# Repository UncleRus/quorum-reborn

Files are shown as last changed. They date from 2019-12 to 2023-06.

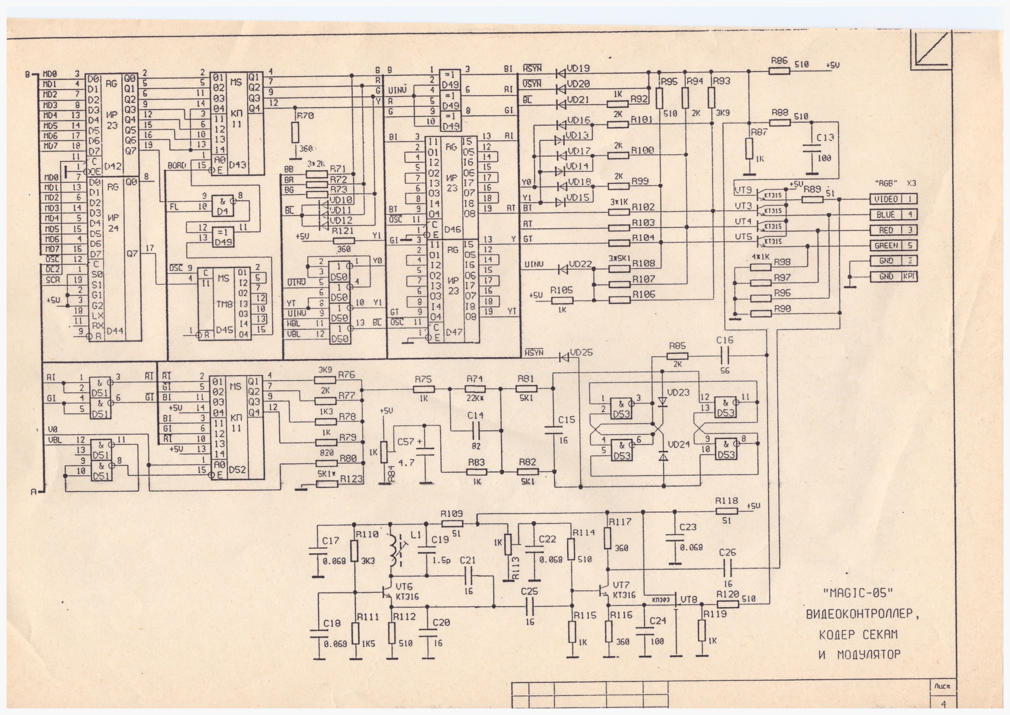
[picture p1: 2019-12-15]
resources/Magic-05/Schematics/Axon/p4.jpg

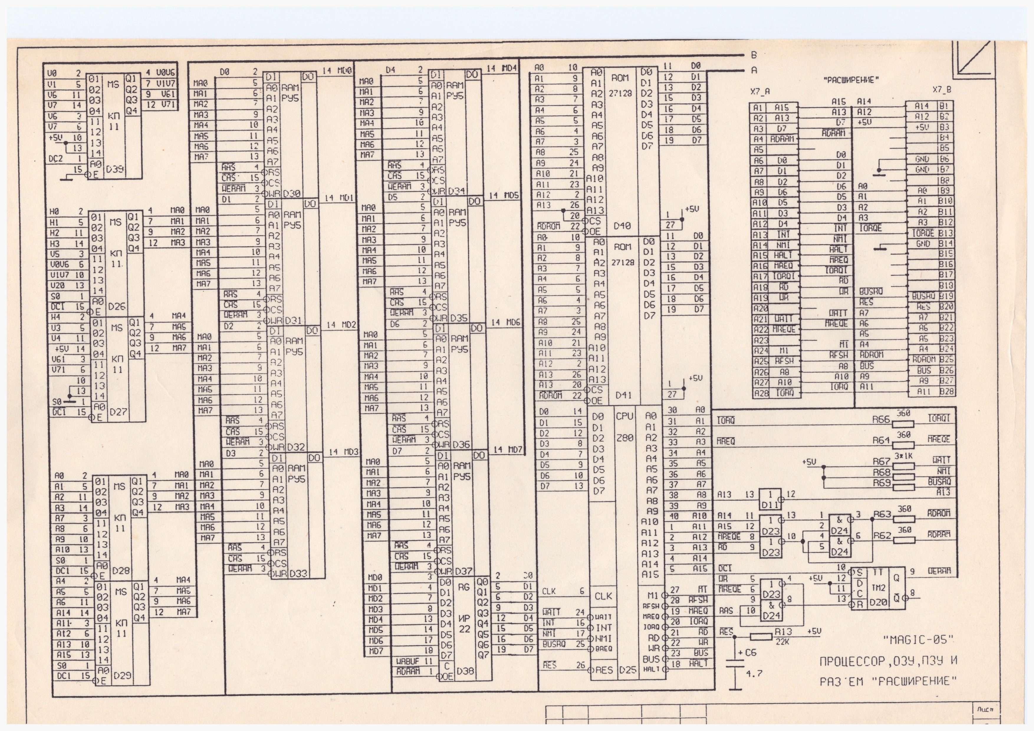
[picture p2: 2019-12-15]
resources/Magic-05/Schematics/Axon/p3.jpg

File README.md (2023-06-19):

# Quorum Reborn

## Russian

[English](#english)

Старая и восстановленная документация для компьютеров ZX Spectrum "Кворум" и "Магик".

### Что такое "Кворум"?

"Кворум" — домашний компьютер, клон ZX Spectrum на советской элементной базе.
Разработан в Свердловске/Екатеринбурге Камилем Каримовым, выпускался заводами
"Вектор", "УОМЗ". Все машины имеют кодер SECAM.

Поддержка "Кворума" встроена в эмуляторы UnrealSpeccy и ZXMAK2.

#### Модели компьютеров

- **Magic-05** — Клон ZX Spectrum 48K с расширенной клавиатурой и портом Centronics.
- **Кворум 64** — Модифицированная версия «Magic-05» с доступным ОЗУ объёмом 64 КБ
   (дополнительные 16 КБ использовались как «теневое» ОЗУ) и измененной адресацией
   дополнительного порта расширенной клавиатуры.
- **Кворум 128** — Клон ZX Spectrum 128K без AY-3-8910. Схема построена на БМК
   КБ01ВГ1-2. В ПЗУ присутствует встроенный тест, монитор и копировщик. Возможность
   работы как в TR-DOS, так и в CP/M. На задней стенке корпуса компьютера располагались
   разъёмы для подключения внешнего блока питания, Kempston и Sinclair джойстиков,
   принтера, магнитофона, телевизора и монитора, а также разъём системной шины для
   подключения внешнего контроллера дисковода.
- **Кворум 128+** — Модификация «Кворум 128» со встроенным 3-дюймовым дисководом,
   контроллером дисковода и звуковым синтезатором AY-3-8910.
- **Кворум БК04** — Выпускался УОМЗ. Клон ZX Spectrum 48K. Имеет кодер SECAM с
   ВЧ-модулятором.
- **Кворум БК05** — Выпускался УОМЗ. Клон ZX Spectrum 48K на БМК КБ01ВГ1-2 и
   однокристальном SECAM-кодере. На плате реализован порт принтера, но отсутствует
   разъем.

### Состав репозитория

- **kicad** - Проекты KiCad для
   - Magic-05,
   - Кворум 64,
   - Кворум 128,
   - Кворум БК04,
   - контроллера дисковода
- **resources** - Старая документация, прошивки, фотографии, софт

### Проекты KiCad

Для работы с ними необходим KiCad версии >= 7.0.
Также в каждом проекте, в подкаталогах /plot лежат схемы, экспортированные в формат PDF.

### Ссылки

https://github.com/atsidaev/quorum-cpm - Исходники CP/M для "Кворума", документация 
по программированию.

## English

Old and restored documentation for ZX Spectrum computers "Quorum" and "Magic".

### What is "Quorum"?

"Quorum" is a home computer, a clone of the ZX Spectrum built with Soviet ICs.
It's developed in Yekaterinburg f.k.a. Sverdlovsk by Kamil Karimov and manufactured by "Vector" and "UOMZ"
factories. All models have built-in SECAM encoder.

Quorum is supported by UnrealSpeccy and ZXMAK2 emulators.

#### The lineup

- **Magic-05** — ZX Spectrum 48K clone with extended keyboard and Centronics port.
- **Quorum 64** — Modified version of "Magic-05" with 64 KB available RAM (additional
   16 KB is used as shadow RAM) and changed addressing of the extended keyboard
   additional port.
- **Quorum 128** — ZX Spectrum 128K clone without the AY-3-8910. The construction 
   is based on KB01VG1-2. The ROM contains a built-in test, monitor and copier.
   It has ability to work in both TR-DOS and CP/M. On the rear side of the computer
   case there were connectors for connecting an external power supply, Kempston and
   Sinclair joysticks, a printer, a tape recorder, a TV and a monitor, as well as a
   system bus connector for connecting an external floppy controller.
- **Quorum 128+** — Quorum 128 modification with a built-in 3-inch drive,
   floppy controller and sound synthesizer AY-3-8910.
- **Quorum БК04** — Produced by UOMZ. ZX Spectrum 48K clone. Has a SECAM encoder with
   RF modulator.
- **Quorum БК05** — Produced by UOMZ. ZX Spectrum 48K clone on BMK KB01VG1-2 and
   single-chip SECAM encoder. The board has a printer port, but no connector.

### Repository contents

- **kicad** - KiCad projects for
   - Magic-05,
   - Quorum 64,
   - Quorum 128,
   - Quorum БК04,
   - Floppy Disk Drive
- **resources** - Old docs, firmware, images, software.

### KiCad Projects

To work with projects you'll need KiCad version >= 7.0.
Also in each project, in the /plot subdirectory there are schematic diagrams 
exported in PDF format.

### Links

https://github.com/atsidaev/quorum-cpm - CP/M sources for Quorum,
development docs.

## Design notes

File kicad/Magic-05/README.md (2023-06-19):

## Схема Magic-05

Проект содержит оригинальную схему Magic-05 с исправленными ошибками без модификаций.

По имеющимся данным компьютер разработан НПО "Интеграл" Сергеем Жаворонковым, Андреем Вычегжаниным, Юрием Серёгиным
под руководством Анатолия Хомени.

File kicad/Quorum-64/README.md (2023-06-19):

## Схема Кворум 64

  - Этот каталог содержит оригинальную схему "Кворум 64" с исправленными ошибками без модификаций
  - Подкаталог `fix-brightness` содержит вариант схемы "Кворум 64" с исправленной ошибкой атрибута яркости у черного

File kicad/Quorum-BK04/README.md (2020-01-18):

## Кворум-БК04

В наличии два варианта схемы: 

- **Quorum-BK04.pro** - Оригинальная заводская схема
- **Quorum-BK04-mods.pro** - Схема с модификациями (порт FF, пентагоновские времянки)

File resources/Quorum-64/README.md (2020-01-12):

## Кворум-64

> Да, это одна и та же схемотехника,кроме адресации дополнительного порта расширенной клавиатуры.
> В Магике (во всех моделях) дополнительный порт адресуется кодом 0xFC, а в Кворумах 0x7E.
> Заводские платы "Магик-5" были доработаны в части адресации этого порта и в них установлены ПЗУ с прошивкой "Кворум 64".
> Особенность прошивки этих моделей именно в части наличия поддержки расширенной клавиатуры, а также русификации, которая также выполнена по-разному.

*Kamil Karimov (Caro)*

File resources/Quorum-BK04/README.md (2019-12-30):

## Кворум БК-04

Первый из серии Кворумов - модель БК-04.
Выпускался УОМЗ (Уральский Оптико-механический завод), с 1992 по 1993 год.
Имеет 48 кб ОЗУ и 16 кб. ПЗУ. Прошивка русифицирована и расчитана на работу с 88-клавишной клавиатурой.
Дополнительная матрица 6*8 подключена через порт 7Eh. Встроенный кодер СЕКАМ и TV-модулятор.

На плате предусмотрено место для распайки стандартного разьема принтера DB25F.
Порты принтера совместимы с ZX-LPrint II. Все процедуры работы с принтером в прошивке переделаны для работы с этим интерейсом.

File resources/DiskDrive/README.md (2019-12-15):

## Схемы контроллера дисковода CP/M-TRDOS для Кворума

1) disk5ram.png - исходная схема, работающая с прошивкой
                  заливаемой в фоновое ОЗУ;
2) disk5emu.png - доработанная схема, работающая и с ОЗУ
                  и с ПЗУ;
3) disk5buf.png - схема буфера;
4) disk5raz.png - размещение элементов контроллера;
5) disk5trd.png - доработанная схема с адресацией портов
                  как в стандартном TRDOS.

*18/05/09*
*Kamil Karimov (caro)*

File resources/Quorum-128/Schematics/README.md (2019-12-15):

## Схема Кворума 128.

Основой схемы является микросхема КБ01ВГ1-2 производства завода Микрон г. Зеленоград.
Используется также микросхема кодера Secam, изготовленная в Екатеринбурге по ТЗ фирмы
"Кворум".

*Kamil Karimov*
*k2k@list.ru*

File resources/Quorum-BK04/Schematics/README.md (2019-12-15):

# Схема и монтажка компьютера "Кворум БК-04"

Разработка фирмы "Кворум" 1991 года.
Производство УОМЗ 1991-1994 гг.

На схеме приведены возможные доработки:

1) обеспечивающие совместимость с времянками Пентагона;
2) порт FF;
3) турбирование за счет ускорения процессора в цикле REFRESH.

*Kamil Karimov (caro)*

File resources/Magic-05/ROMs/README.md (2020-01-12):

## Прошивки для Magic-05

- MAGIC5_1.ROM - последняя версия прошивки, предоставлена Камилем Каримовым
- magic91.rom - вариант прошивки, предоставлен Камилем Каримовым
- magic5_1092350.rom - прошивка, считанная с ПЗУ компьютера с серийным номером 1092350

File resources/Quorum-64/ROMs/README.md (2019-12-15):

# Прошивки для "Кворума БК-04" производства УОМЗ и "Кворум 64" производства ПО Вектор.

 - QU4i1993.rom - только BASIC
 - QU4v93t4.rom - Basic и TR-DOS 5.04T не эмулятор
 - QU4v93tb.rom - Basic и TR-DOS 5.03E эмулятор
 - Quorum_64_08930726.rom - Прошивка, считанная с Кворума-64 с серийным номером `08 93 0726`

В прошивке Basic для работы с контроллером дисковода (с точкой в заставке BASIC) предусмотрен
"горячий" выход в TRDOS по нажатию клавиши NMI с предварительно нажатой клавишей Caps Shift.

*Kamil Karimov (caro)*
*14.04.2009*

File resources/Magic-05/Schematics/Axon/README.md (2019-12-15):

## Схема Магика-05

Схема предоставлена AlexCrush

### Ошибки

Схема содержит ряд ошибок:

 - Лист P1:
   
   - Неверные имена сигналов: HSIN, /HSIN, VSIN, /VSYN. 
     Должно быть: HSYN, /HSYN, VSYN, /VSYN соответственно.

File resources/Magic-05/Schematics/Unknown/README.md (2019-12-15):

## Magic-05

Еще один вариант схемы. Взят с форума https://zx-pk.ru

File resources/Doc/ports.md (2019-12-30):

# Порты Кворумов

Хотя при адресации портов используется неполная дешифрация адреса,
рекомендуется использовать указанные ниже адреса устройств при разработке 
своих программ.

## Порт управления памятью
Адрес **00H** [A7,A4,A0,/IORQ = 0]

Назначение разрядов порта (только запись):

- **D0 (F_RAM)** - управление фоновой страницей ОЗУ
  - 0 - включено ПЗУ
  - 1 - включена 0-ая страница ОЗУ
- **D1 (UP_S)** - (только для Кворум 64 с дисководом) переключатель страниц видео-ОЗУ
  - 0 - нижняя страница (4000H..5AFFH)
  - 1 - верхняя страница (C000H..DAFFH)
- **D2 (EX_ROM)** - (только для Кворум 128, в '128+' нет) управление расширенным ПЗУ (до 32 Кбайт)
  - 0 - включено основное ПЗУ
  - 1 - включено дополнительное ПЗУ
- **D3** - резерв
- **D4** - резерв
- **D5 (B_ROM)** - (в Кворум 64 не используется) разрешение BASIC-страницы ПЗУ
  - 0 - включена дополнительная страница ПЗУ
  - 1 - включена BASIC-страница ПЗУ
- **D6 (BLK_WR)** - (для Кворум 64 требуется доработка) блокировка записи в фоновое ОЗУ
  - 0 - запись в адреса с 0000..3FFFH разрешена
  - 1 - запись заблокирована, только чтение
- **D7 (TR_DOS)** - разрешение работы TRDOS из ПЗУ
  - 0 - TRDOS работает из фонового ОЗУ
  - 1 - разрешена работа из ПЗУ

## Порт Sрectrum 128
Адрес **7FFDH** [A15,A1,/IORQ = 0; A3,A4 = 1]

Назначение разрядов порта (только запись):

- **D0..D2 (NP_RAM)** - номер страницы ОЗУ, отображаемой на адреса
  с 0C000H до 0FFFFH
- **D3 (SCR_P)** - (для Кворум 128, 128+ в режиме BASIC) переключатель страниц видео-ОЗУ
  - 0 - нижняя страница (4000H.. в ОЗУ-5)
  - 1 - верхняя страница (C000H.. в ОЗУ-7)
- **D4 (B_PAG)** - управление страницами BASIC-ПЗУ
  - 0 - BASIC-128
  - 1 - BASIC-48
- **D5 (BLK_P)** - блокировка записи в порт SP_128
  - 0 - запись разрешена
  - 1 - запись заблокирована (снятие по сбросу)
- **D6 (EX_RAM)** (только для Кворум 256)
  - 0 - основное ОЗУ
  - 1 - дополнительный блок на 128 Кбайт
- **D7 (E2_RAM)** (только для Кворум 512)

## Порт CP/M
Адрес **80FDH** [A13,A1,/IORQ = 0; A15,A4,A3 = 1]

Этот порт реализован в ULA, используемом в Кворум 128 и Кворум 128+.
Запись в него разрешена только в случае первого обращения к нему после
начального сброса.

Назначение разрядов порта (только запись):

- **D0..D2 (NP_SCR)** - переключатель адреса начала видео-ОЗУ 
   (только в Кворум 128, 128+ в режиме CP/M)
  - 000 - 4000H
  - 001 - 6000H
  - 010 - 8000H
  - 011 - A000H
  - 100 - C000H
  - 101 - E000H
  - 110 - 0000H
  - 111 - 2000H
- **D3..D6** - не используются
- **D7 (EN_RAM)** - разрешение работы с фоновым ОЗУ
  - 0 - запрет работы с фоновым ОЗУ
  - 1 - в фоновое ОЗУ разрешена запись

## Порты клавиатуры

### Основной порт
Адрес **FEH** [A0,/IORQ = 0; A7,A4,A3 = 1]

Назначение разрядов порта (чтение):

- **D0..D4** - разряды сканирования клавиатуры
- **D5** - не используется (всегда 1)
- **D6** - разряд чтения с магнитофона
- **D7** - не используется (всегда 1)

Назначение разрядов порта (запись):

- **D0..D2** - код цвета бордюра
- **D3** - разряд записи на магнитофон
- **D4** - разряд управления звуком
- **D5..D7** - не используется

### Дополнительный порт
Адрес **7EH** [A7,A0,/IORQ = 0; A4,A3 = 1]

Назначение разрядов порта (чтение):

- **D0..D5** - разряды сканирования клавиатуры
- **D6..D7** - не используется (всегда 1)

## Порты контроллера дисковода

### Порт состояния/команд ВГ93
Адрес **80H** [A4,A3,A2,A1,A0,/IORQ = 0; A7 = 1]

### Порт номера текущей дорожки ВГ93
Адрес **81H** [A4,A3,A2,A1,/IORQ = 0; A7,A0 = 1]

### Порт номера сектора ВГ93
Адрес **82H** [A4,A3,A2,A0,/IORQ = 0; A7,A1 = 1]

### Порт данных ВГ93
Адрес **83H** [A4,A3,A2,/IORQ = 0; A7,A1,A0 = 1]

### Порт управления дисководом
Адрес **85H** [A4,A3,/IORQ = 0; A7,A2 = 1]

Назначение разрядов порта:

- **D0 (SEL_0)** 
  - 1 - выборка устройства A:
- **D1 (SEL_1)**
  - 1 - выборка устройства B:
- **D2 (резерв SEL_2)**
  - 1 - выборка устройства C:
- **D3 (резерв SEL_3)**
  - 1 - выборка устройства D:
- **D4 (SIDE)** - выбор стороны дискеты
  - 0 - верхняя головка дисковода
  - 1 - нижняя головка дисковода
- **D5 (MOTOR)**
  - 1 - включить привод дисковода
- **D6..D7** - резерв

## Порт Кэмпстон-джойстика.
Адрес **1FH** [A7,/IORQ = 0; A4,A3,A0 = 1]

Назначение разрядов порта (только чтение):

- **D0..D4** - разряды джойстика
  (при не подключенном джойстике всегда 0)
- **D5..D6** - не используется (всегда 0)
- **D7** - разряд готовности принтера
  (при не подключенном принтере всегда = 0)

## Порты принтера.

### Порт данных
Адрес **FBH** [A2,/IORQ = 0; A7,A4,A3,A0 = 1]

Запись в этот порт устанавливает линию 'Строб' в 1.

Назначение разрядов (только на запись):

**D0..D7** - байт данных, пересылаемый в принтер

### Порт формирователя строба
Адрес **7BH** [A7,A2,/IORQ = 0; A4,A3,A0 = 1]

Запись в этот порт устанавливает линию 'Строб' в 0.

### Порт готовности принтера
Адрес **1BH** [A7,/IORQ = 0; A4,A3,A0 = 1]

Назначение разрядов (только чтение):

- **D0..D6** - не используются (всегда 0)
- **D7** - линия готовности принтера
  - 0 - принтер готов
  - 1 - принтер занят

## Порты музыкального сопроцессора.

### Порт адресации регистров AY-3-8910/12

Адрес **FFFDH** [A1,/IORQ =0; A15,A14,A13,A4,/M1 = 1]

### Порт данных AY-3-8910/12

Адрес **BFFDH** [A14,A1,/IORQ =0; A15,A13,A4,/M1 = 1]

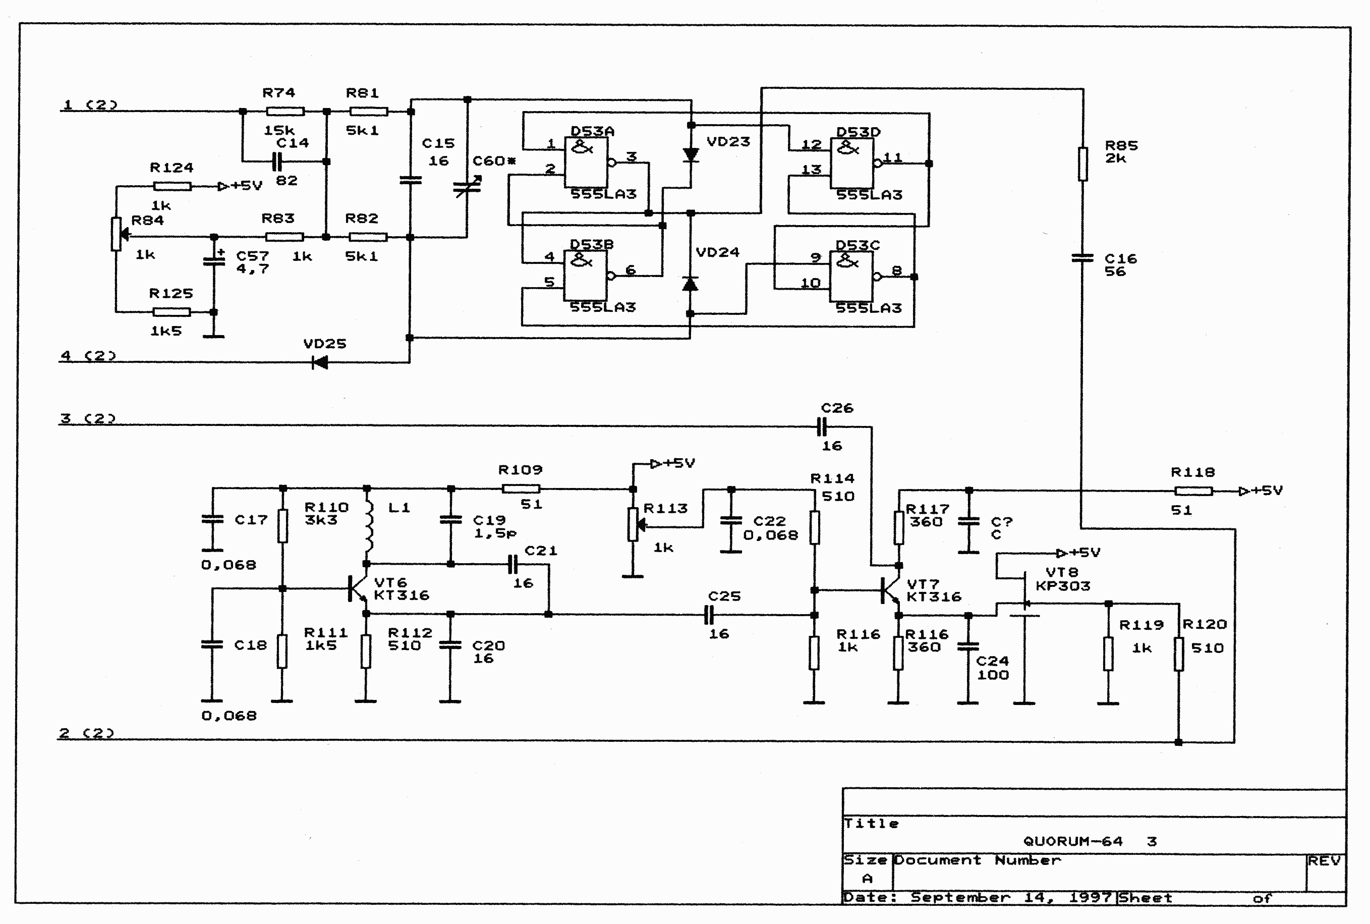
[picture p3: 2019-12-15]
resources/Quorum-64/Schematics/QU64_3.PNG

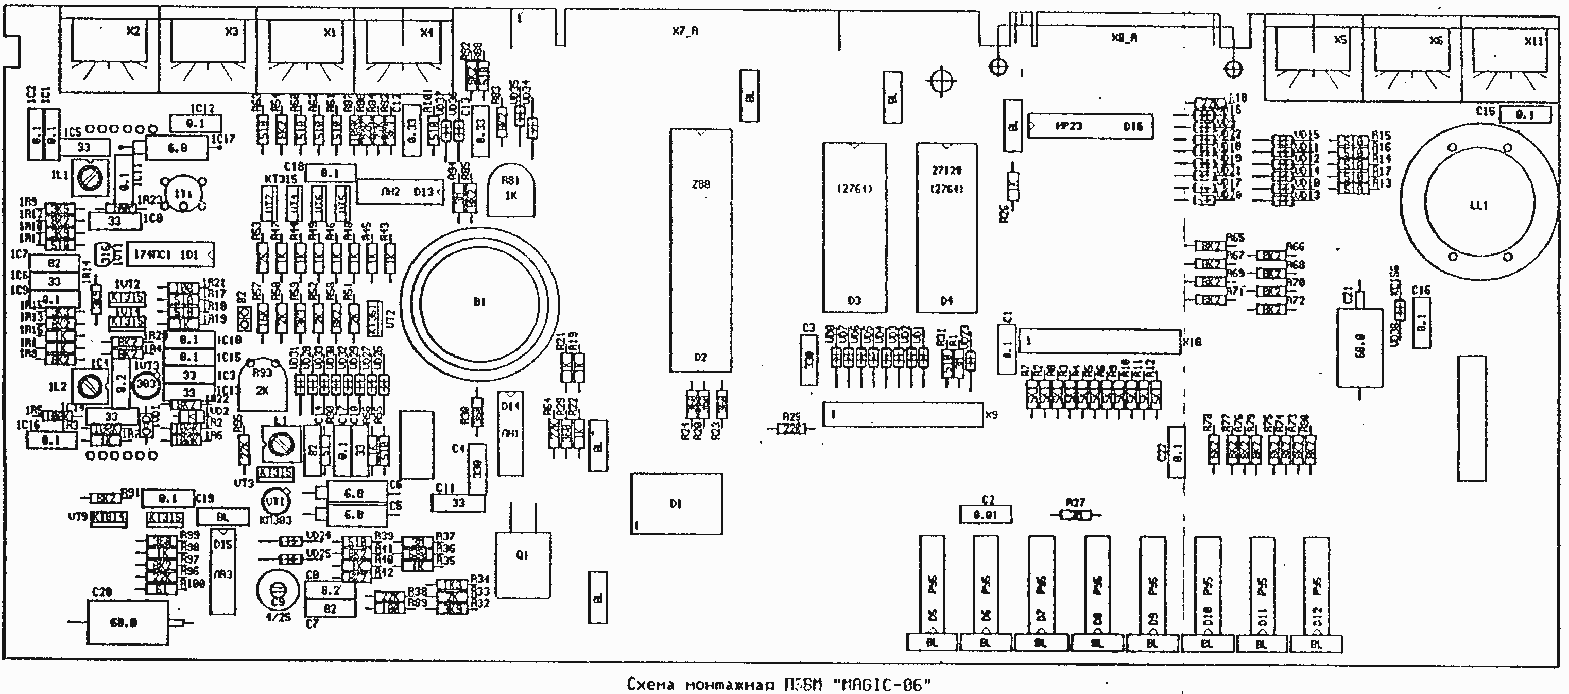
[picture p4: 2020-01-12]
resources/Magic-06/Schematics/magic6_3.png

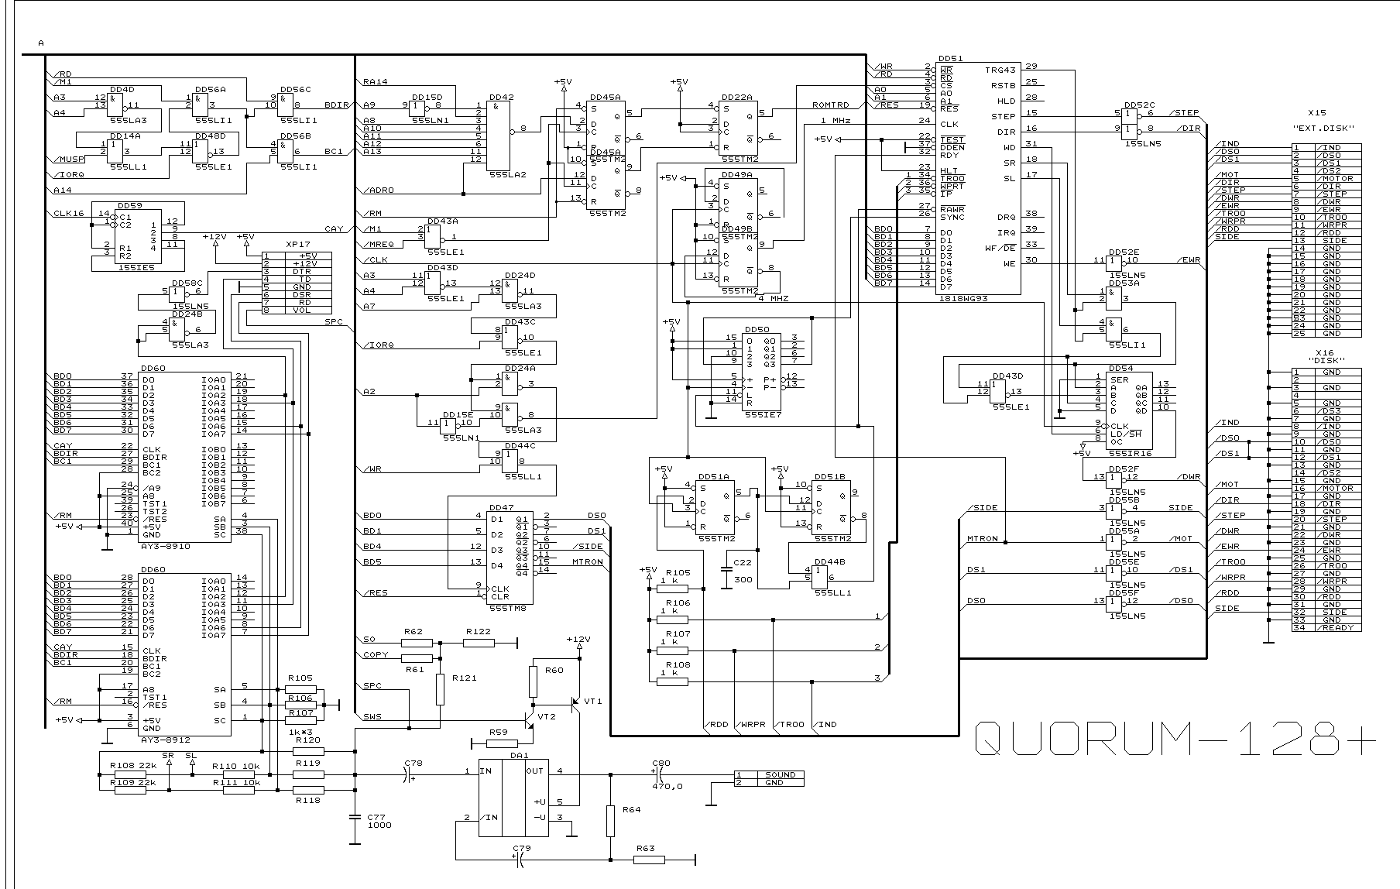
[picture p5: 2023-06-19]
resources/Quorum-128+/Schematics/TRDOS.png

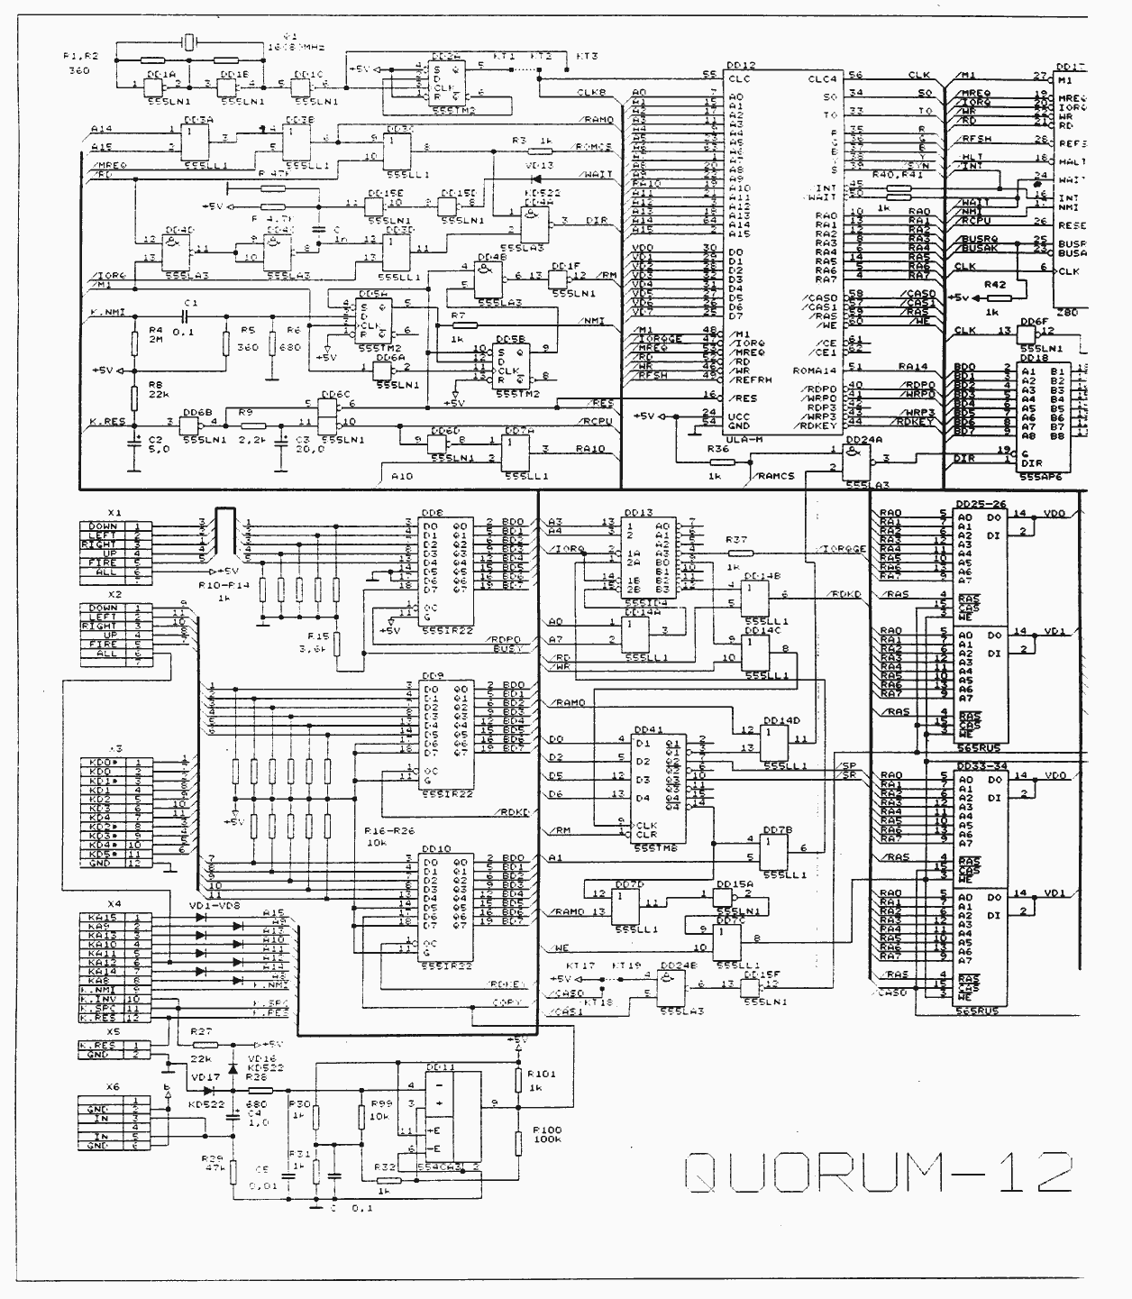
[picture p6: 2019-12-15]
resources/Quorum-128/Schematics/Q128P1M.PNG

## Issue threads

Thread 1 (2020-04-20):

Неверная фотография Кворум-БК04

AlexCrush, 2020-04-20:
Вместо фото БК04 фотография Magic-05

AlexCrush, 2020-04-20:
Вот тут https://github.com/UncleRus/quorum-reborn/blob/master/resources/Quorum-BK04/Photo/2(real).jpg

UncleRus, 2020-04-24:
Спасибо!

Closed 2020-04-24.

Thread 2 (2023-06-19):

Разные варианты схемы Q128

UncleRus, 2023-06-19:
Собственно, в наличии два варианта схемы Кворума-128:
1. https://github.com/UncleRus/quorum-reborn/blob/master/resources/Quorum-128/Schematics/Q128P1M.PNG
    https://github.com/UncleRus/quorum-reborn/blob/master/resources/Quorum-128/Schematics/Q128P2M.PNG
2. https://github.com/UncleRus/quorum-reborn/blob/master/resources/Quorum-128/Schematics/ULA.png

Нужно понять, какая именно из них является действительной. Прошу владельцев Кворума-128 помочь в этом вопросе.

atsidaev, 2023-06-19:
ULA.png, судя по подписи - это схема от Кворума-128+. Еще на ней светодиод питания (на Кворуме-128 его нет) и БП, выдающий не только 5 вольт, но и 12 (которые нужны 128+ для ВГ93 но не нужны простому 128). Правда, насколько помню, у БП 128+ напряжения должны быть выше, 9 и 17 нестабилизированных вольт, но возможно, что внутри компа стоит ещё одна доп. плата с кренками (ну типа как у БК-04).

UncleRus, 2023-06-19:
Спасибо большое! Схему от 128+ перенес в отдельный каталог.

Closed 2023-06-19.

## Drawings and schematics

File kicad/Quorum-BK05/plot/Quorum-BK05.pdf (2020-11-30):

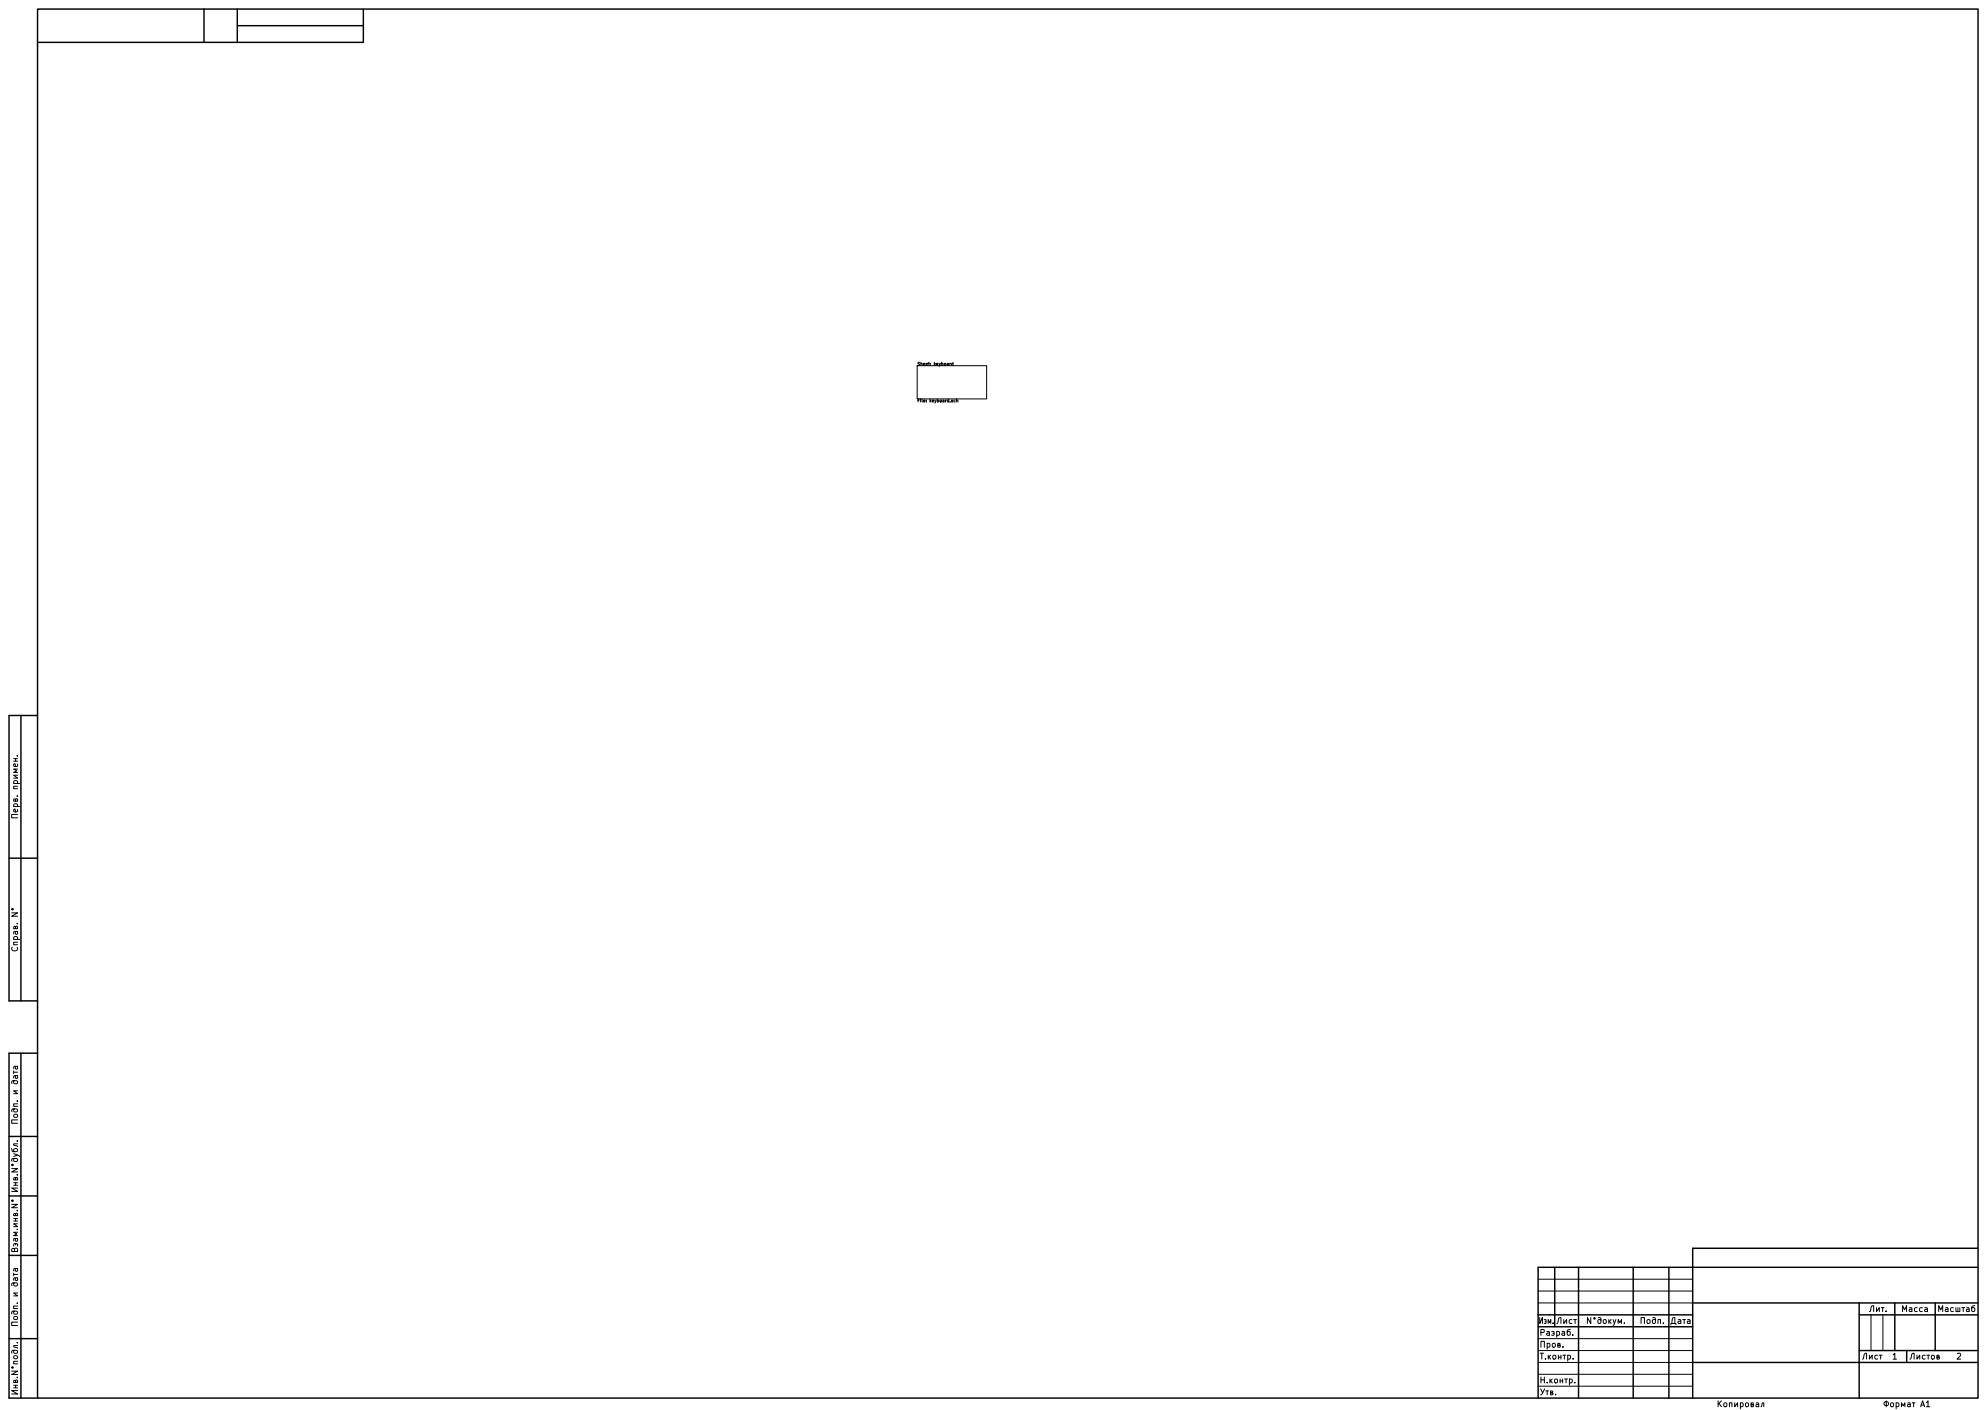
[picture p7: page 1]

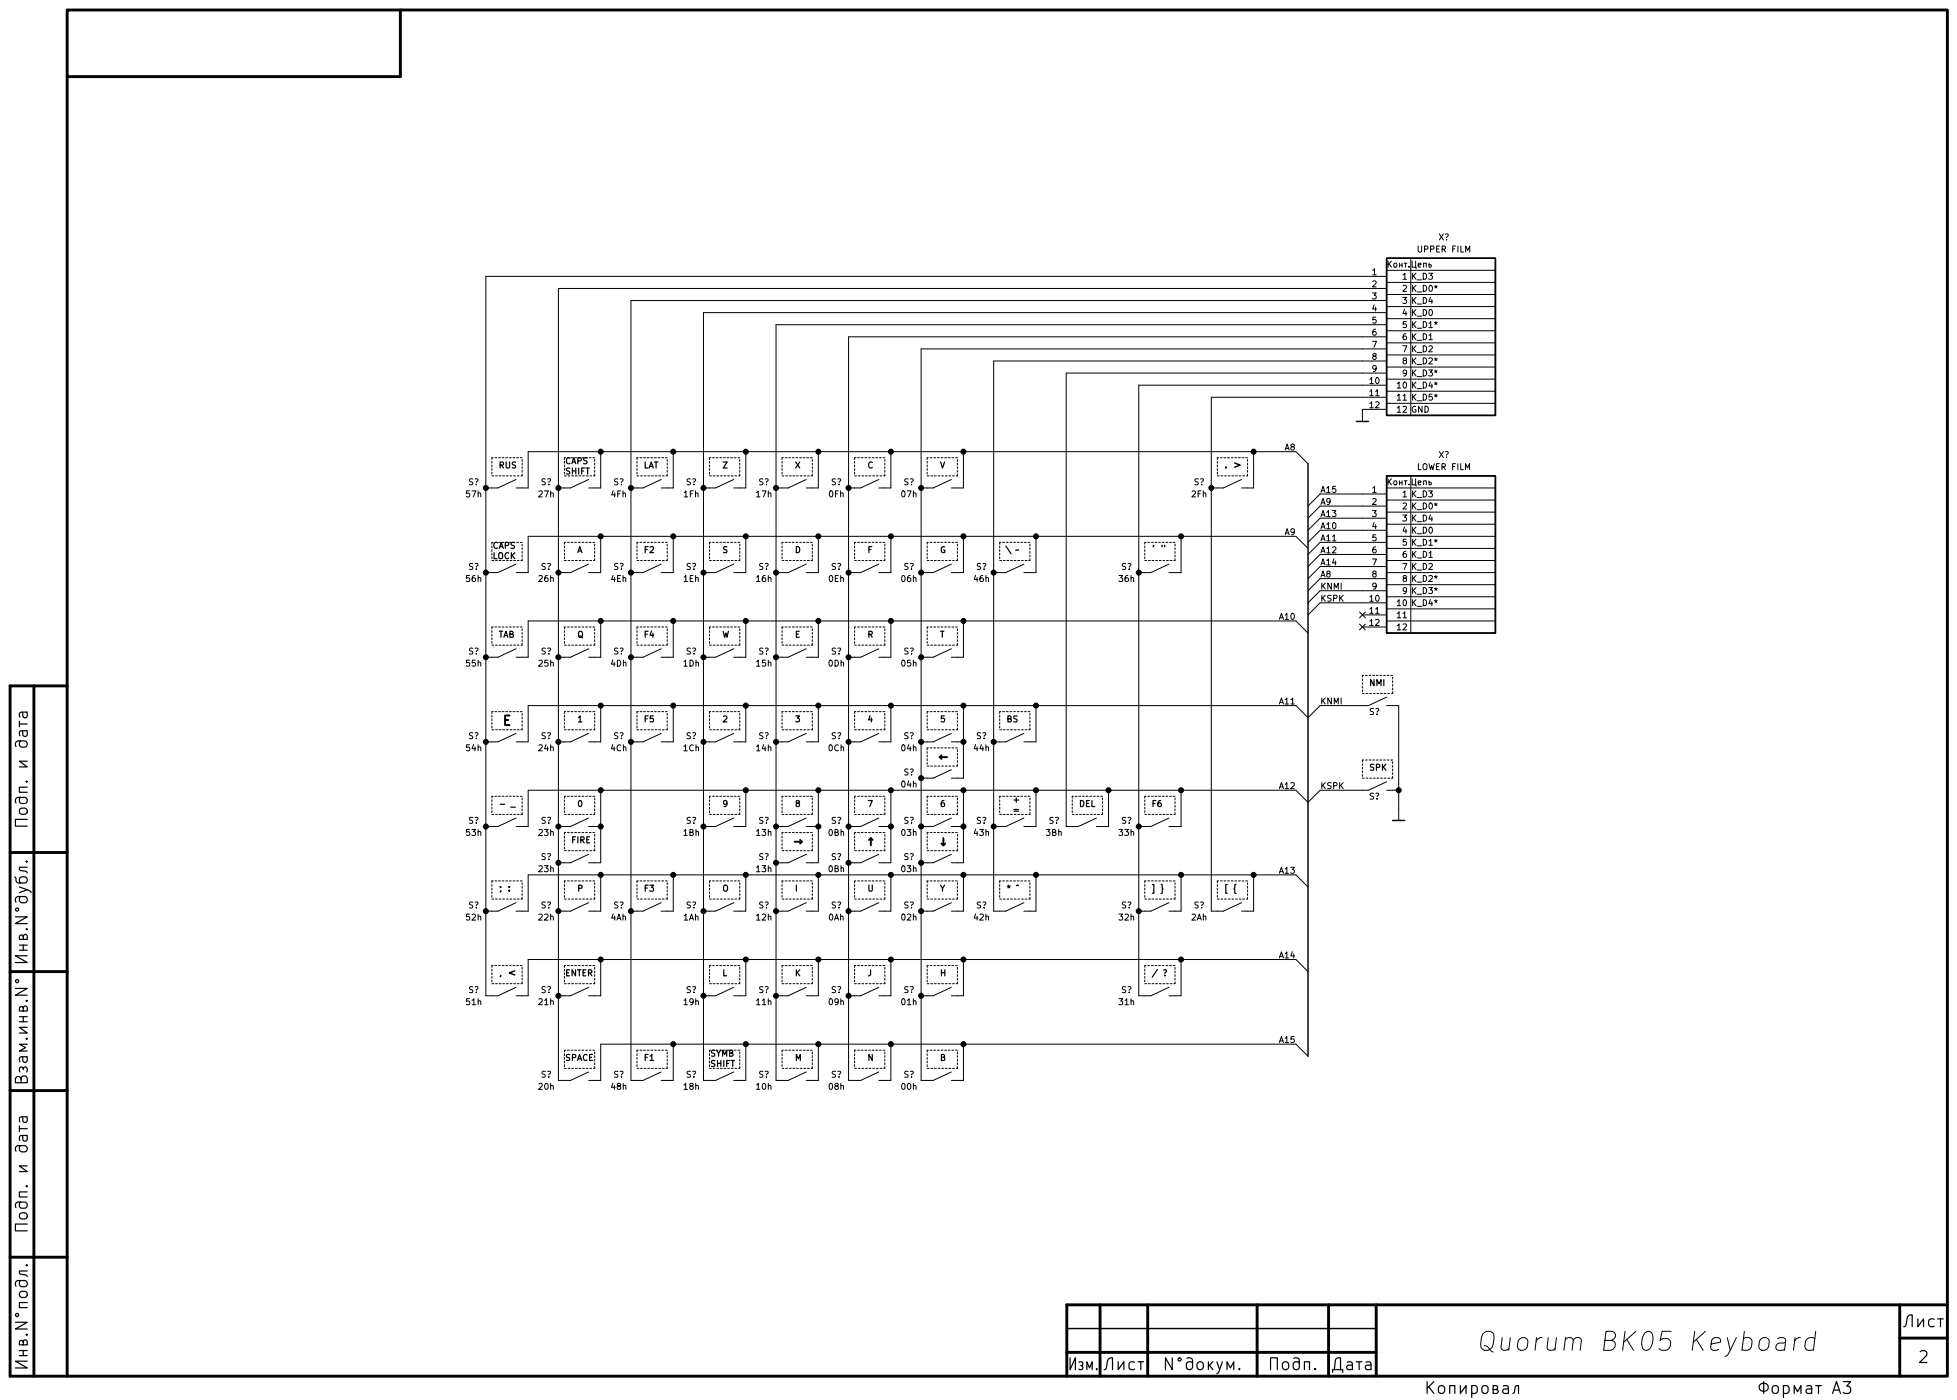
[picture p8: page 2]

1223456789. 1
K_D3 K_D0* K_D4 K_D0 K_D1* K_D1 K_D2 K_D2* K_D3* K_D4* K_D5* GND

10
11

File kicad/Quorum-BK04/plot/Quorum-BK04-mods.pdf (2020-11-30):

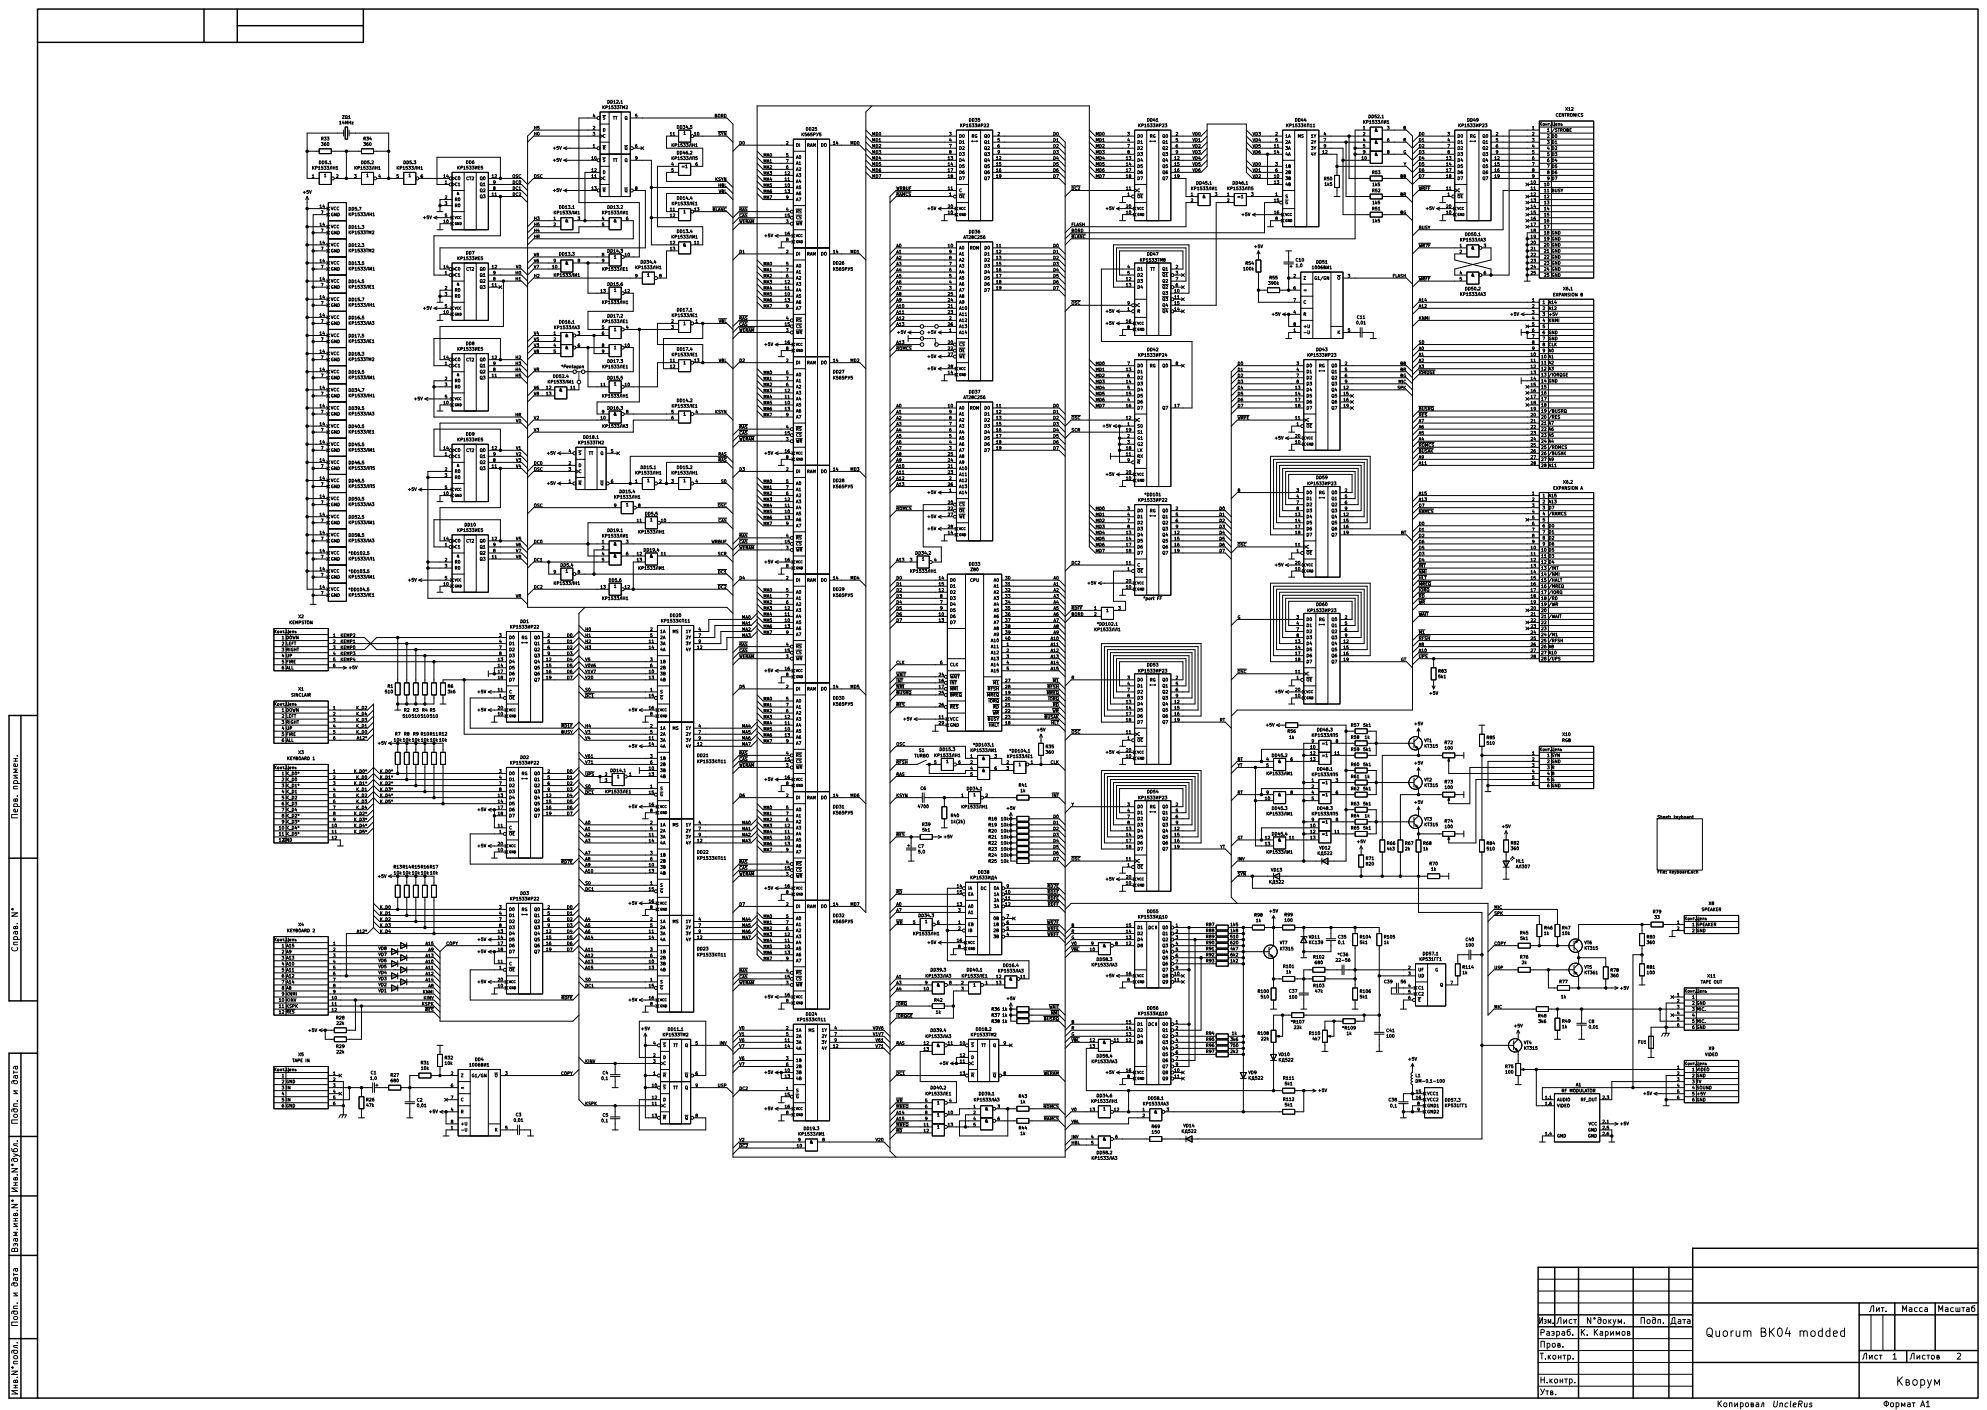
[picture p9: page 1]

/STROBE D0 D1 D2 D3 D4 D5 D6 D7 BUSY GND GND GND GND GND GND GND GND 1

MS | 2Y | 7 GND 8

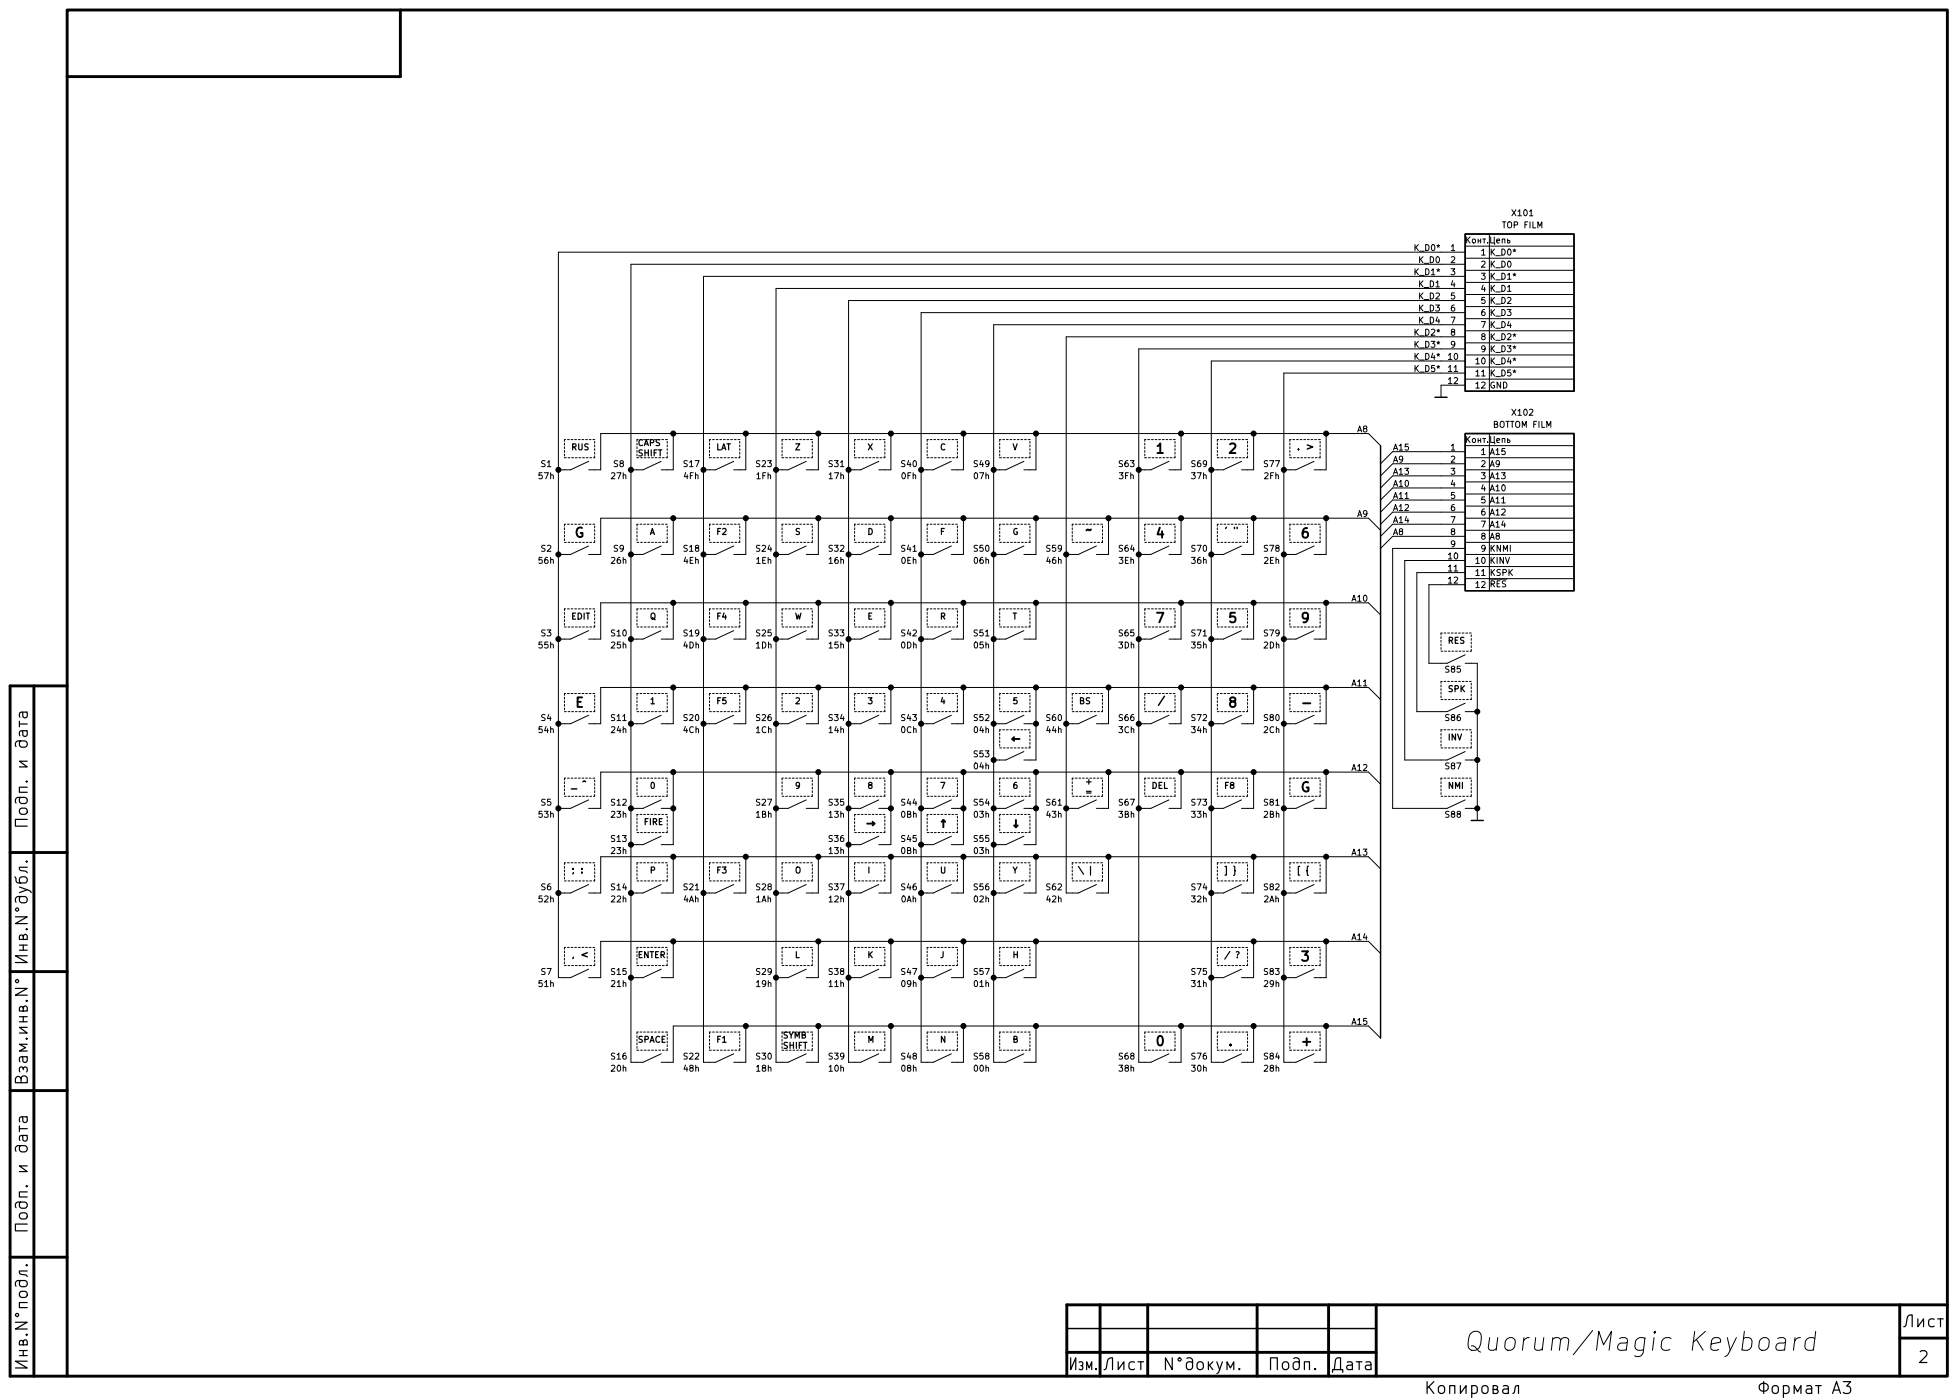
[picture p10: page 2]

1223456789. 1
K_D0* K_D0 K_D1* K_D1 K_D2 K_D3 K_D4 K_D2* K_D3* K_D4* K_D5* GND

10
11

11 | KSPK RES

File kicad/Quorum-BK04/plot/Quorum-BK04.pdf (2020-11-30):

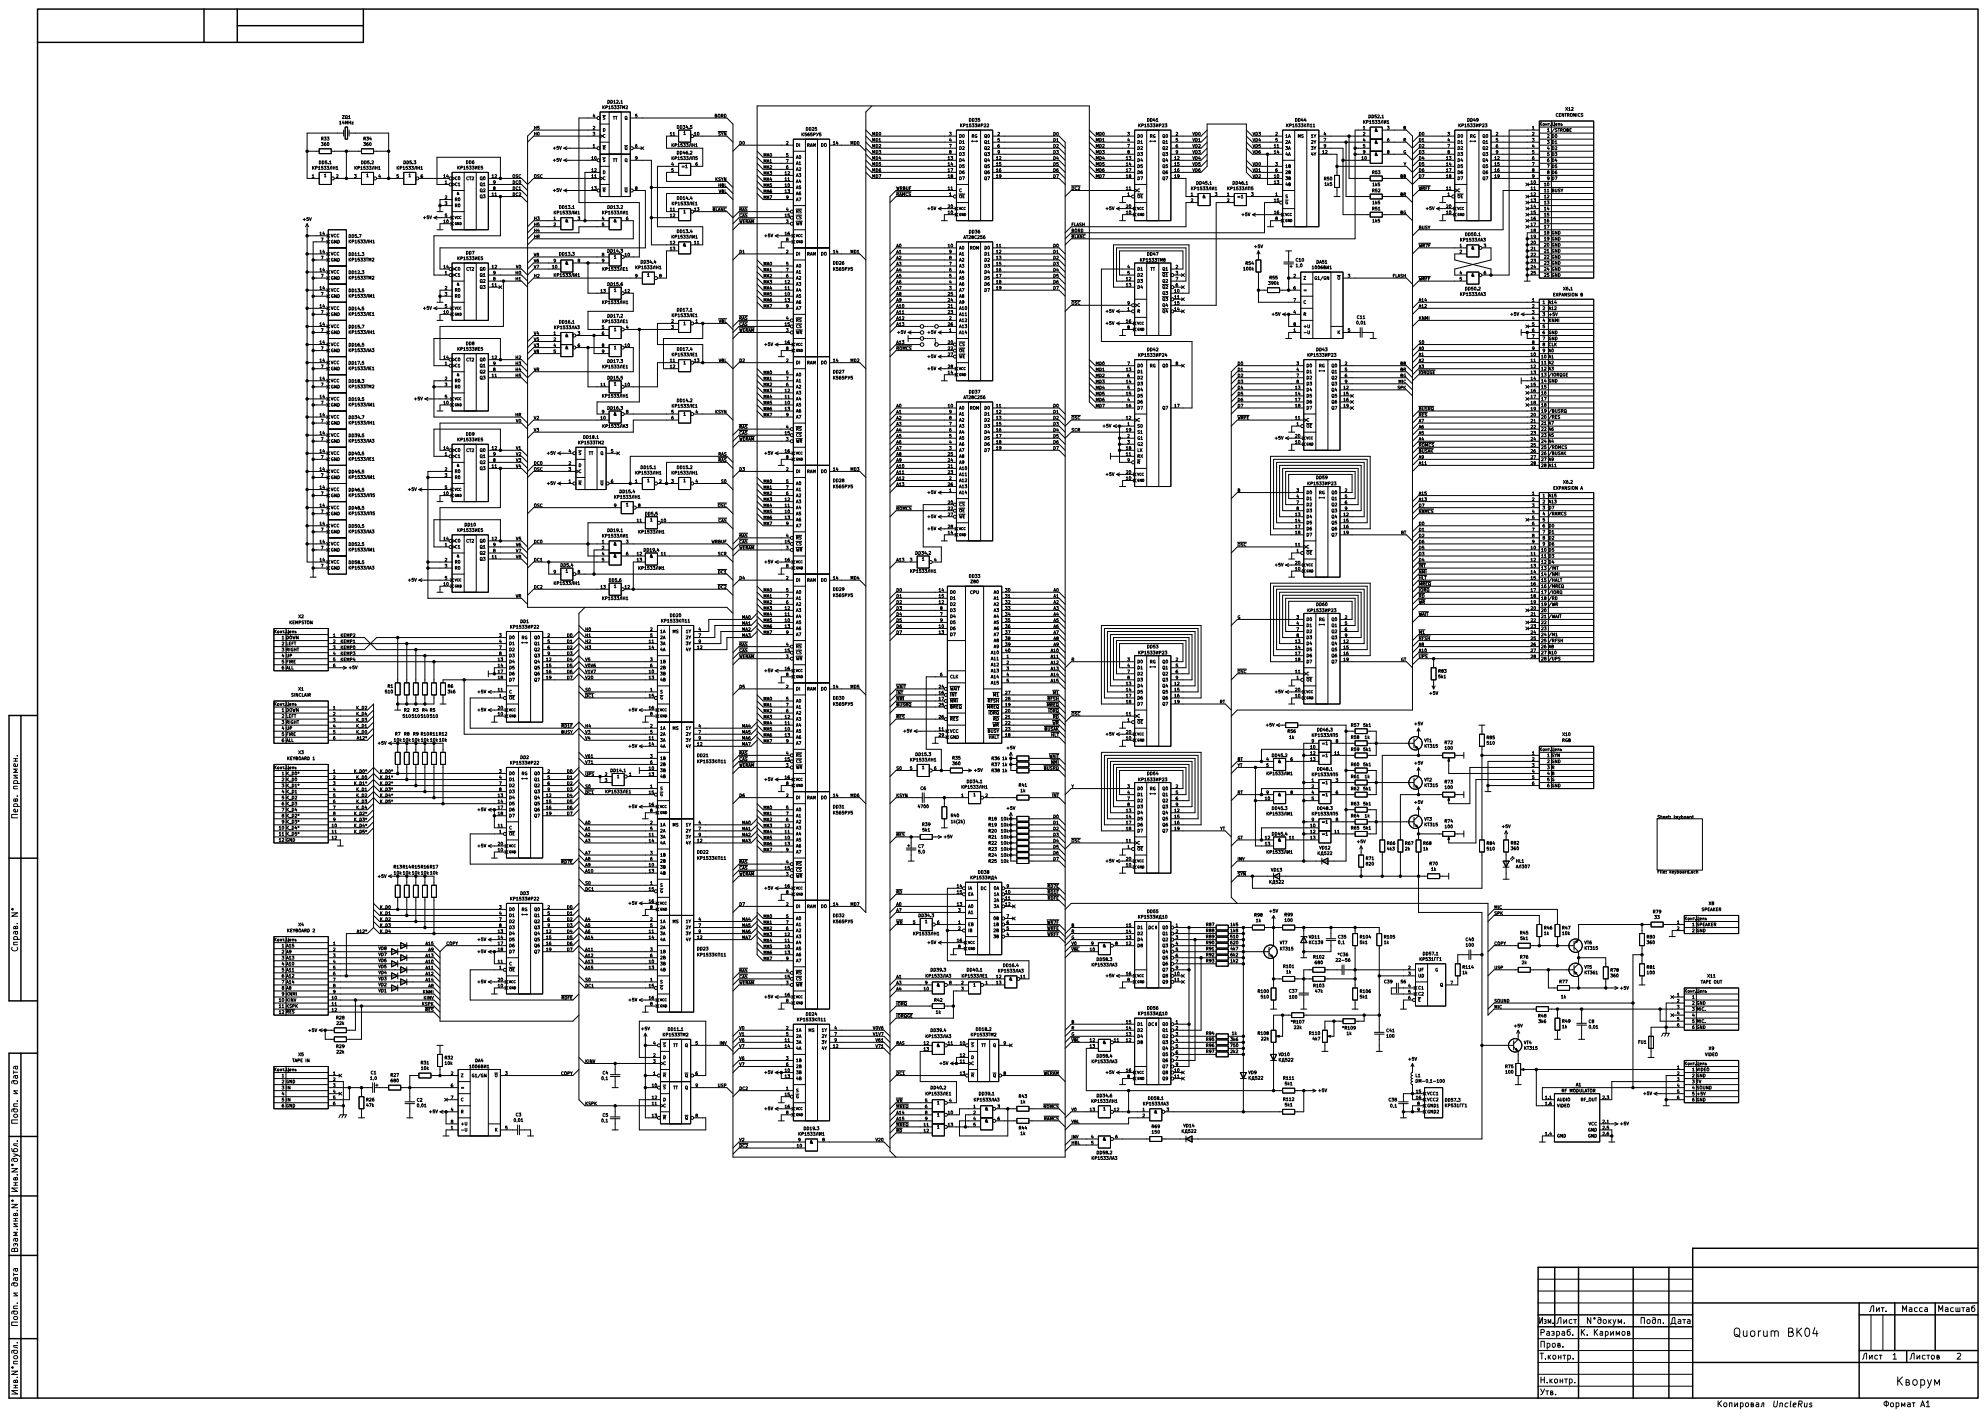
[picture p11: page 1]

10 | /STROBE D0 D1 D2 D3 D4 D5 D6 D7 BUSY GND GND GND GND GND GND GND GND 1
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
KNMI GND GND

13 | /IORQGE GND

25 | /ROMCS
26 | /BUSAK

/RAMCS D0 D1 D2 D6 D5 D3 D4

13 | /INT
14 | /NMI
15 | /HALT
16 | /MREQ
17 | /IORQ
18 | /RD
/WR
20
21 | /WAIT
22
23
24 | /M1

25 | /RFSH
26 | A8A10
27


1223456789. 1
K_D0* K_D0 K_D1* K_D1 K_D2 K_D3 K_D4 K_D2* K_D3* K_D4* K_D5* GND

10
11

11 | KSPK RES

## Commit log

2019-12-15 Initial upload
    [Magic-05.sch, Magic-05_fixed.sch, Quorum-64.sch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]
2019-12-28 Комментарии к reborn, мелкие правки в q64
    [Quorum-64.sch, Quorum-Reborn.kicad_pcb, Quorum-Reborn.sch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]
2019-12-28 Добавлен вариант прошивки Magic-05, в reborn добавлены блокирующие C
    [Quorum-Reborn.kicad_pcb, Quorum-Reborn.sch]
2019-12-30 Описание портов приведено в удобочитаемый вид
2019-12-30 Исправлена ошибка в KiCad схеме Magic-05
    [Magic-05.sch, Magic-05_fixed.sch]
2019-12-30 Краткое описание БК-04
2019-12-31 Исправлена ошибка в KiCad схеме Кворум 64
    [Quorum-64.sch, Quorum-64_fixed.sch, keyboard.sch]
2019-12-31 Мелкие правки KiCad и README
    [Quorum-64.sch, Quorum-64_fixed.sch]
2019-12-31 Исправлена распиновка разъема расширения в KiCad схеме Кворума 64
    [Quorum-64.sch, Quorum-64_fixed.sch]
2019-12-31 Слот расширения в схеме Magic-05 проверен по реальному компьютеру
    [Magic-05.sch, Magic-05_fixed.sch]
2020-01-03 Исправлены ошибки в KiCad схемах M-05, Q-64
    [Magic-05.sch, Magic-05_fixed.sch, Quorum-64.sch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]
2020-01-07 Добавлен KiCad проект Кворума-128
    [Quorum-128.sch, Quorum-bk05.sch, bk05_mtg.sch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]
2020-01-07 Удалил новодел
    [Quorum-Reborn.kicad_pcb, Quorum-Reborn.sch, keyboard.sch]
2020-01-07 Правка README
2020-01-07 Удалил мусор
    [Quorum-bk05.sch, bk05_mtg.sch, ~Quorum-128.sch]
2020-01-08 Добавил перемычки в схему Q128
    [Quorum-128.sch]
2020-01-08 Мелкие правки в схемах Q64 и M05
    [Magic-05.sch, Magic-05_fixed.sch, Quorum-64.sch]
2020-01-08 Исправлено начертание разъемов в схемах
    [Magic-05.sch, Magic-05_fixed.sch, Quorum-128.sch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]
2020-01-12 Q128: исправлены ошибки в схеме, M06: добавлен ROM и схема в другом формате
    [Quorum-128.sch]
2020-01-12 M05: вариант ПЗУ
2020-01-12 Q64: Добавлена заметка Caro
2020-01-15 KiCad-проект Кворум БК-04
    [Quorum-BK04.sch, keyboard.sch]
2020-01-18 BK04: Исправлены ошибки, добавлен вариант с модификациями
    [Quorum-BK04-mods.sch, keyboard.sch]
2020-01-18 BK04: Добавлен README
2020-01-18 Исправлена ошибка нумерации выводов РУ5
    [Quorum-128.sch, Quorum-64.sch, Quorum-BK04-mods.sch]
2020-01-18 M05, Q64: исправлены ошибки подключения RAM
    [Magic-05.sch, Magic-05_fixed.sch, Quorum-64.sch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]
2020-01-21 FDD: KiCad проект контроллера FDD
    [quorum_disk_drive_emu.sch]
2020-01-21 Мелкие правки
    [Magic-05.sch, Magic-05_fixed.sch, Quorum-128.sch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]
2020-01-21 DD: Схема буфера и контроллера дисковода
    [buffer.sch, quorum_disk_drive_emu.sch]
2020-01-22 DDemu: исправлены ошибки в схеме и буфере, сгененрирован PDF
    [buffer.sch, quorum_disk_drive_emu.sch]
2020-01-31 BK04: мелкие правки
    [Quorum-BK04-mods.sch, Quorum-BK04.sch]
2020-02-22 Q64: добавлен вариант модификаций, DD: плата
    [Quorum-128.sch, Quorum-64_fixed.sch, Quorum-64_fixed2.sch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]
2020-11-30 Обновлены УГО разъемов, исправлены множественные ошибки в схемах клавиатур
    [Magic-05.sch, Magic-05_fixed.sch, Quorum-128.sch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]
2020-11-30 Добавлена схема клавиатуры для БК05
    [Quorum-BK05.sch, keyboard.sch]
2020-12-01 Q64, M05: перекомпонованы схемы, all: исправлены ошибки в клавиатурах
    [Magic-05.sch, Magic-05_fixed.sch, Quorum-64.sch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]
2023-06-19 Добавлены схемы Q-128 в улучшенном качестве
2023-06-19 DD, M05, Q64, Q128: проекты KiCad обновлены до версии 7.0
    [Magic-05.kicad_sch, Magic-05.sch, Magic-05_fixed.sch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]
2023-06-19 Q128: исправлен проект KiCad
    [Quorum-128.kicad_sch, keyboard.kicad_sch]
2023-06-19 Q128+: Выделена схема Кворум-128+
2023-06-19 Q128+: Добавлены фотографии
2023-12-30 m-05: Добавлено руководство по эксплуатации Magic 5
